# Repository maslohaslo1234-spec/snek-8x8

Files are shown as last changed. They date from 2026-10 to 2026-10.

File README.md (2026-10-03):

# Snek 8x8

A pocket-sized arcade console powered by an ESP32. It runs Snake on an 8x8 LED matrix and Flappy Bird on a 128x64 OLED display, with button controls, sound, and saved high scores.

ob

This project is being built for [Hack Club Half Life](https://halflife.hackclub.com/).

## Features

- Snake and Flappy Bird
- Three difficulty levels
- Optional walls in Snake, bonus food, and a high-score table
- High scores and settings saved between reboots
- English and Polish interface with a saved language preference
- Menu and in-game music, sound effects, and an idle screensaver

## Hardware

- ESP32 development board
- 8x8 LED matrix driven by two 74HC595 shift registers
- SSD1306 128x64 I2C OLED display
- Five push buttons on the PCB design; the current firmware uses three for game and menu controls.
- Buzzer
- Li-Po battery and power components

### Pin connections

| Part | ESP32 pin |
| --- | --- |
| 74HC595 data | GPIO 23 |
| 74HC595 latch | GPIO 16 |
| 74HC595 clock | GPIO 18 |
| OLED SDA | GPIO 21 |
| OLED SCL | GPIO 22 |
| SW1 (Up) | GPIO 33 |
| SW2 (Down) | GPIO 27 |
| SW3 (Left) | GPIO 14 |
| SW4 (Right) | GPIO 13 |
| SW5 (Action) | GPIO 26 |
| Buzzer control | GPIO 25 |

The button pins use `INPUT_PULLUP` and are wired between GPIO and GND, so pressed is LOW. SW1 and SW2 are sampled only to track activity and wake the screensaver; they do not control a game or menu. Check the pinout for your specific ESP32 board before wiring it. The buzzer is driven through a BC547 NPN transistor with a 1 kOhm base resistor; GPIO HIGH turns the buzzer on. Make sure the display, matrix drivers, and ESP32 share GND.

| Switch | GPIO | Planned function | Used by current firmware (yes/no) |
| --- | --- | --- | --- |
| SW1 | GPIO 33 | not used yet, reserved for Up/Down | No |
| SW2 | GPIO 27 | not used yet, reserved for Up/Down | No |
| SW3 | GPIO 14 | Left | Yes |
| SW4 | GPIO 13 | Right | Yes |
| SW5 | GPIO 26 | Action | Yes |

Here, "used" means used as a game or menu control; SW1 and SW2 are still sampled for activity/screensaver wake.

The 8x8 LED matrix was hand-soldered by me from a DIY kit.

### Hardware (work in progress)

[Schematic draft (PDF)](hardware/exports/snek_pcb_kicad.pdf)

Status: schematic draft v0.1 (power, charging, 5 buttons, buzzer, OLED, LED matrix), PCB layout not started.

The power design uses a Li-Po battery, a TP4056 charger module, a slide switch, and a 5V step-up converter. A Schottky diode is on the step-up output, which powers the ESP32 VIN pin.

## Controls

| Button | Snake | Flappy Bird |
| --- | --- | --- |
| Left | Turn left | Pause |
| Right | Turn right | Not used |
| Action | Pause; press again to resume | Flap |

While paused, hold Action for about one second to return to the menu. In menus, Left and Right move through the options and Action selects one. Change the interface language in Settings; the selection is saved between reboots.

Up and Down are reserved for a future full-D-pad update; they do not currently control Snake, Flappy Bird, or the menus.

## Build and upload

1. Install the Arduino IDE and the ESP32 board support package by Espressif.
2. Install the **Adafruit SSD1306** and **Adafruit GFX Library** libraries using the Arduino IDE Library Manager. `Wire` and `EEPROM` are provided by the ESP32 Arduino core.
3. Open `firmware/esp32_snake/esp32_snake.ino`. Keep the other `.ino` files in the same folder; the Arduino IDE uses them as part of the sketch.
4. Select your ESP32 board and port, then build and upload.

The firmware uses the ESP32 Arduino core 3.x timer API. If compilation fails around `timerBegin`, `timerAttachInterrupt`, or `timerAlarm`, check that the installed ESP32 core is version 3.x.

## Repository layout

- `firmware/esp32_snake/` - current ESP32 firmware
- `legacy/arduino_snake/` - earlier Arduino firmware, kept for reference
- `hardware/` - KiCad schematic/project files and `hardware/exports/` for schematic exports

## Project log

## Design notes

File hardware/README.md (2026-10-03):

# Hardware

The schematic defines the planned hardware for the Snek 8x8 console:

- ESP32
- 8x8 LED matrix driven by two 74HC595 shift registers
- SSD1306 OLED
- Buzzer driven through a BC547 transistor
- Five push buttons (SW1-SW5)
- Li-Po battery, TP4056 charger module, slide switch, 5V step-up converter, and a Schottky diode on the step-up output

[View the schematic PDF](./exports/snek_pcb_kicad.pdf).

**Status:** schematic draft v0.1, PCB layout not started, nothing on the PCB has been built or tested yet.

## differences between hardware design and firmware

- The schematic has five buttons, but only SW3 (Left), SW4 (Right), and SW5 (Action) are used as game/menu controls. SW1 (Up) and SW2 (Down) are sampled only for activity/screensaver wake; they do not control a game or menu yet.
- The schematic includes the battery charging and power-conversion components, but the firmware contains no battery or charging management/monitoring code.

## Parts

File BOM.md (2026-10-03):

# Snek 8x8 — bill of materials

<!-- Generated by Half Life from project cmup66916042c01s1dxs5xl8g. Edits here are overwritten on the next sync. -->
<!-- Generated: 2026-10-03T12:50:23.381Z -->

> [!NOTE]
> This parts list is mirrored from [Half Life](https://halflife.hackclub.com). Editing it here will not change the platform's copy, and the next sync overwrites this file.

| Week | Tier | Parts funding |
| --- | --- | --- |
| Warm-up | Tier 1 | $30.00 |

| Part | What it's for | Qty | Unit | Total | Vendor |
| --- | --- | --- | --- | --- | --- |
| [3.7V 1400mAh Li-Po Battery (Akyga)](https://botland.com.pl/akumulatory-li-pol-1s-37v/14160-akumulator-akyga-li-pol-1400mah-1s-37v-zlacze-jst-bec-gniazdo-54x34x7mm-5904422321970.html) | Main power source for the console | 1 | $6.50 | $6.50 | [Botland](https://botland.com.pl/akumulatory-li-pol-1s-37v/14160-akumulator-akyga-li-pol-1400mah-1s-37v-zlacze-jst-bec-gniazdo-54x34x7mm-5904422321970.html) |
| [Li-Po Charger Module TP4056 USB-C](https://botland.com.pl/ladowarki-do-akumulatorow-li-ion/16979-ladowarka-li-ion-hw-373-v121-tp4056-pojedyncza-cela-1s-37v-usb-typ-c-z-zabezpieczeniami-5904422326708.h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) | Charging the battery and over-discharge protection | 1 | $1.42 | $1.42 | [Botland](https://botland.com.pl/ladowarki-do-akumulatorow-li-ion/16979-ladowarka-li-ion-hw-373-v121-tp4056-pojedyncza-cela-1s-37v-usb-typ-c-z-zabezpieczeniami-5904422326708.h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) |
| [Slide Switch 2-position](https://botland.com.pl/przelaczniki-suwakowe-i-przesuwne/4839-przelacznik-suwakowy-mss-2245-2-pozycyjny-prosty-5904422304188.html) | Main power ON/OFF switch | 1 | $1.01 | $1.01 | [Botland](https://botland.com.pl/przelaczniki-suwakowe-i-przesuwne/4839-przelacznik-suwakowy-mss-2245-2-pozycyjny-prosty-5904422304188.html) |
| [Female Pin Headers](https://botland.com.pl/gniazda-szpilkowe-goldpin/20029-listwa-goldpin-1x40-zenska-raster-254mm-10szt-justpi-5904422329174.html) | Sockets for ESP32, OLED, and Matrix so they are removable from the PCB | 1 | $2.55 | $2.55 | [Botland](https://botland.com.pl/gniazda-szpilkowe-goldpin/20029-listwa-goldpin-1x40-zenska-raster-254mm-10szt-justpi-5904422329174.html) |
| [Custom PCB](https://jlcpcb.com) | Main circuit board connecting ESP32, OLED, LED matrix, TP4056 charger, and controls | 1 | $2.00 | $2.00 | [JLCPCB](https://jlcpcb.com) |
| [5V Step-Up Voltage Regulator](https://botland.com.pl/przetwornice-step-up/3686-przetwornica-step-up-5v-12-a-z-gniazdem-usb-5903351241304.html) | Steps up 3.7V Li-Po battery voltage to stable 5V for ESP32 it has USB because it was the cheapest | 1 | $1.34 | $1.34 | [Botland](https://botland.com.pl/przetwornice-step-up/3686-przetwornica-step-up-5v-12-a-z-gniazdem-usb-5903351241304.html) |
| [Miscellaneous Components](https://botland.com.pl) | Transistors, connectors, resistors, and basic circuit parts | 1 | $3.00 | $3.00 | [Botland](https://botland.com.pl) |
| **Parts subtotal** | — | — | — | **$17.82** | — |
| **Tax & shipping** | — | — | — | **$12.00** | — |
| **Total** | — | — | — | **$29.82** | — |

$0.18 left of the tier's funding.

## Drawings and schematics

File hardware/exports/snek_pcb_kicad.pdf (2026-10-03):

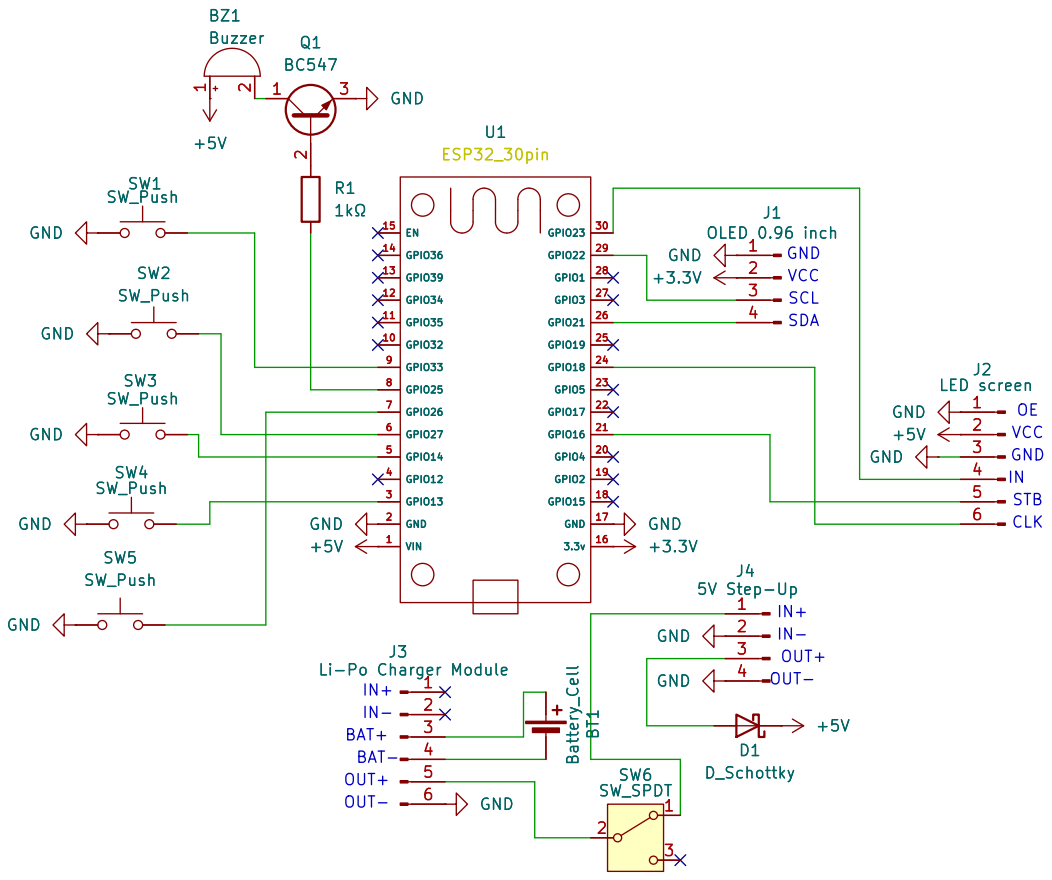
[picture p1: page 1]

Li-Po Charger Module 1

Size: A4 | Rev:
KiCad E.D.A. 10.0.6 | Id: 1/1

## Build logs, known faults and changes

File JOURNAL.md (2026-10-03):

# Snek 8x8 — devlog

<!-- Generated by Half Life from project cmup66916042c01s1dxs5xl8g. Edits here are overwritten on the next sync. -->
<!-- Generated: 2026-10-03T14:29:23.751Z -->

> [!NOTE]
> This devlog is mirrored from [Half Life](https://halflife.hackclub.com). Editing it here will not change the platform's copy, and the next sync overwrites this file.

> I'm building a pocket-sized handheld console that plays Snake on an 8×8 LED matrix, powered by an ESP32. The matrix isn't an off-the-shelf module. I soldered it myself from a DIY kit, LED by LED, which taught me a lot about how matrix displays are wired and driven. The console also has an OLED for score and menus and a buzzer for sound effects. The firmware is already fairly advanced: it has menus, sound and a two-language interface (Polish and English). I should be upfront that most of the code was written with AI assistance, because programming is not my strong side. My part of the project is the hardware: the soldering, wiring, electronics design and enclosure. That's also what I want to get better at in this program. I already have a working prototype on a breadboard. Now I want to turn it into a real, portable device: 	•	a custom PCB with the ESP32, the LED matrix, OLED, buzzer, buttons  	•	a 3D-printed enclosure designed in CAD, with a D-pad and action    buttons, 	•	clean power and wiring, so it works without a breadboard. My goal is to learn the full path from prototype to finished product: schematic, PCB layout, enclosure design and assembly. Parts: ESP32, hand-soldered 8×8 LED matrix, 0.96" OLED, buzzer, tact switches,  PCB, 3D-printed case.

| Week | Tier | Hours logged | Entries |
| --- | --- | --- | --- |
| Warm-up | Tier 1 | 14.5h | 3 |

## Contents

1. [2026-10-01 — ### Soldering the 8x8 LED matrix kit](#2026-10-01-soldering-the-8x8-led-matrix-kit)
2. [2026-10-01 — # From a dead chip to a playable console](#2026-10-01-from-a-dead-chip-to-a-playable-console)
3. [2026-10-03 — # Designing my first PCB: From breadboard to KiCad](#2026-10-03-designing-my-first-pcb-from-breadboard-to-kicad)

## Design

### 2026-10-01 — ### Soldering the 8x8 LED matrix kit

**3.5h**

### Soldering the 8x8 LED matrix kit

Bought a new soldering iron and wanted to test it, so I got a cheap Chinese practice kit: A41Z-DIY, a 64-LED SMD dot matrix board.

board

 No plan to build a game — just wanted to solder it and see if it worked. Soldered everything except the LEDs first

T,R

 then all 64 of them — only to find I'd put every single one in backwards. Desoldered and redid all 64

LEDs

 Then realized I'd lost the U1 chip that was supposed to drive the test animations, I couldn't actually test the board.

U1

kit

kit1

### 2026-10-01 — # From a dead chip to a playable console

**7h**

# From a dead chip to a playable console

After I lost the U1 chip from my kit, I realised the board still had header pins (OE, VCC, GND, IN, STB, CLK) connected directly to the two 74HC595 shift registers. That meant I could skip the missing chip and drive the matrix myself.

Jumper wires connected to the header pins of the matrix board

I connected an Arduino Nano and wrote a test sketch to turn on every LED. I was sure I had killed a few of them while soldering and desoldering, so seeing all 64 light up was a big surprise.

All 64 LEDs lit up during the Nano test sketch

With a working matrix and a few buttons on the breadboard, the obvious next step was Snake. I couldn't fit a plus-shaped D-pad on the breadboard layout, so the first version used just two buttons for relative movement (turn left / turn right).

First version of Snake running on the matrix

### Score, sound, and menus

I needed a place to show the score, so I added a 0.96" I2C OLED display. At first, it caused strange refresh problems and flickering. I fixed it by moving the matrix scanning into a hardware timer interrupt, writing to the shift registers using a custom fast shift-out function instead of `shiftOut()`, and swapping the frame buffer with interrupts temporarily disabled so a half-updated frame is never rendered.

OLED showing the score

Next came the buzzer: first a simple looping melody, then I found code for the Super Mario theme online and adapted it. That was easy, so I added Megalovania and the Tetris theme too.

Buzzer added to the breadboard

With several tracks, I needed a menu, so I built a simple UI on the OLED (one button moves the cursor, the other confirms). After that, I added three difficulty levels, two wall modes (walls kill you vs. wrap around), and bonus food spawning.

### Moving to ESP32

The Nano eventually became too limiting, so I moved everything to an ESP32. This was harder than I expected: the AVR timer tricks don't exist on the ESP32, so I had to rewrite the timer interrupt using the ESP32's native timer API. Also, to fix broken audio timing caused by the ESP32's 32-bit architecture, I removed the AVR-specific `PROGMEM` and `pgm_read_word()` calls, reading the note arrays directly from memory.

Circuit rebuilt around the ESP32

The upgrade was definitely worth it:
A third button: menus now use Right = Up, Left = Down, and Third = OK (in Snake, the controls still turn left/right). The third button also pauses the game, and a long press on the pause screen returns to the main menu.
Screensavers: idle animations run on both the OLED and the matrix when the console is left untouched.

Pause screen on the OLED

### Flappy Bird (a side experiment)

Once the ESP32 was running, I wanted a second game to see how flexible the system was. I picked Flappy Bird, but on an 8x8 matrix it's almost unplayable: the screen is only 8 pixels tall, so there's no room to see incoming pipes. My fix was rendering the game on **both displays at the same time**.

Flappy Bird shown on the OLED

Controls use the same setup: the action button flaps, and the left button pauses. It's less polished than Snake, so I treat it as a side experiment, but it proved the console can host multiple games.

### Saving data

High scores and settings are stored with the `EEPROM` library and `EEPROM.commit()`, so they survive power loss. Sound settings are stored separately for the main menu and for in-game audio.

### Where it stands

The whole prototype works, but it's still a tangle of breadboard wires:

The complete breadboard prototype on my desk

**Next step:** designing a custom PCB so everything works without the breadboard.

### 2026-10-03 — # Designing my first PCB: From breadboard to KiCad

**4h**

# Designing my first PCB: From breadboard to KiCad

Playing on the breadboard was becoming almost impossible because of all the loose wires constantly disconnecting, so I decided it was finally time to design a custom PCB.

I started out in EasyEDA. Since this was my first time ever creating a circuit schematic, I forgot quite a few basic things at the beginning, but I eventually managed to get a working draft.

First schematic draft in EasyEDA



Next, I wanted to try out KiCad, which had also been recommended to me. I started by recreating roughly the same schematic I had built in EasyEDA to get used to the software. In this version, I upgraded the controls to a 5-button setup: 4 buttons for a full D-pad and 1 action button.

KiCad schematic in progress

image_b0f565

While working on it, I realized it would be awesome to make the console fully portable by adding a battery and integrated charging. I hesitated at first, wondering if power management would make the design too complicated for my very first PCB, but I decided it was worth a shot.

Timelapse of designing the schematic in KiCad

polaczony-ezgif.com-video-to-gif-converter

I updated the schematic by adding a Li-Po battery connection, a TP4056 charger module, a 5V step-up voltage regulator to keep a stable supply for the ESP32, and a 2-position slide switch for power control.

Finished KiCad schematic with battery and power management

Zrzut ekranu 2026-10-03 154936

Next: PCB layout and routing

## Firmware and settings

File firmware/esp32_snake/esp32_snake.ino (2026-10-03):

#include <Wire.h>
#include <EEPROM.h>
#include <Adafruit_GFX.h>
#include <Adafruit_SSD1306.h>
#include <esp_system.h>
#include "pins.h"

#define SCREEN_WIDTH 128
#define SCREEN_HEIGHT 64
#define OLED_RESET -1
Adafruit_SSD1306 display(SCREEN_WIDTH, SCREEN_HEIGHT, &Wire, OLED_RESET);

const unsigned long BUTTON_DEBOUNCE_MS = 120;
const unsigned long IDLE_TIMEOUT_MS = 30000;
const unsigned long HOLD_EXIT_MS = 1000;
const int SPEED_UP_EVERY_FOODS = 4;
const int SPEED_UP_STEP_MS = 15;
const int MIN_GAME_SPEED_MS = 90;

// EEPROM address map.
const size_t EEPROM_SIZE = 36;
const byte EEPROM_MAGIC = 0xA8;
const int EEPROM_ADDR_MAGIC = 0;
const int EEPROM_ADDR_DIFFICULTY = 1;
const int EEPROM_ADDR_WALLS = 2;
const int EEPROM_ADDR_MUSIC_MENU = 3;
const int EEPROM_ADDR_MUSIC_GAME = 4;
const int EEPROM_ADDR_LANGUAGE = 5;
const int EEPROM_ADDR_HIGHSCORE_EASY = 8;
const int EEPROM_ADDR_HIGHSCORE_MED = 12;
const int EEPROM_ADDR_HIGHSCORE_HARD = 16;
const int EEPROM_ADDR_HIGHSCORE_FLAPPY = 20;

byte currentGame = 0; // 0: Snake, 1: Flappy Bird

byte snakeX[64];
byte snakeY[64];
byte snakeLen = 3;
byte foodX = 0;
byte foodY = 0;

byte bonusFoodX = 0;
byte bonusFoodY = 0;
bool isBonusFoodActive = false;
unsigned long bonusFoodTimer = 0;
const unsigned long BONUS_FOOD_DURATION_MS = 6000;
byte foodEatenCount = 0;

int score = 0;
int highScores[3] = {0, 0, 0}; // Snake: easy, medium, hard.
int highScoreFlappy = 0;
int currentDir = 1; // 0: up, 1: right, 2: down, 3: left.
bool dirChangedThisTick = false;
int gameSpeed = 350;
int scoreMultiplier = 1;
unsigned long gameStartTime = 0;
unsigned long gameEndTime = 0;
bool isNewHighScore = false;

bool gameStarted = false;
bool isPaused = false;
bool isGameOver = false;
bool isWinner = false;
bool isScreensaver = false;
bool oledDirty = true;

byte menuState = 0;              
byte mainMenuCursor = 0;         
byte settingsCursor = 0;
byte muzykaCursor = 0;           

byte difficultySetting = 1;
bool wallsEnabled = true;
byte languageSetting = 0; // 0: English, 1: Polish.

byte musicMenuTrack = 0;
byte musicGameTrack = 1;
byte currentPlayingTrack = 255;

const byte FB_PIPE_COUNT = 3;
float fbBirdY = 32;
float fbBirdVel = 0;
bool fbFlapQueued = false;
int fbPipeX[3];
int fbGapY[3]; // Vertical center of each gap.
int fbGapSize = 22;
int fbPipeW = 16;
int fbScrollSpeed = 2;
int fbBirdX = 28;
unsigned long lastFlappyFrame = 0;  

int ssX = 40, ssY = 28;
int ssDirX = 1, ssDirY = 1;
unsigned long lastSsMoveTime = 0;
const byte SS_TRAIL_LEN = 12;
int ssTrailX[12];
int ssTrailY[12];
int ssFoodX = 90, ssFoodY = 40;
int ssFoodDirX = -1, ssFoodDirY = 1;
byte ssMatFoodX = 7, ssMatFoodY = 3;
int ssMatFoodDir = 1;
byte ssMatFoodPos = 10;

bool isDeathAnimating = false;
byte deathAnimStep = 0;
unsigned long lastDeathAnimTime = 0;

bool lastLeftState = HIGH;
bool lastRightState = HIGH;
bool lastActionState = HIGH;
bool lastUpState = HIGH;
bool lastDownState = HIGH;
unsigned long lastActivityTime = 0;
unsigned long pauseActionPressTime = 0;
bool pauseExitTriggered = false;
bool pauseInputArmed = false; // Wait for ACTION to be released after entering pause.

unsigned long lastMoveTime = 0;
unsigned long lastButtonTime = 0;
unsigned long lastBlinkTime = 0;
bool blinkState = true;

unsigned long sfxEndTime = 0;
unsigned long lastMusicNoteTime = 0;
int currentMusicNoteIndex = 0;
unsigned long currentNoteDuration = 0;
bool isPlayingGameOverJingle = false;
unsigned long lastOledUpdateTime = 0;
const unsigned long OLED_UPDATE_MS = 35;

volatile byte displayBuffer[8];
volatile byte currentScanRow = 0;

void IRAM_ATTR writeMatrix(byte rows, byte columns);
void clearMatrixBuffer();
void setupMatrixTimer();

void setup() {
  pinMode(DATA_PIN, OUTPUT);
  pinMode(LATCH_PIN, OUTPUT);
  pinMode(CLK_PIN, OUTPUT);

  pinMode(BTN_LEFT_PIN, INPUT_PULLUP);
  pinMode(BTN_RIGHT_PIN, INPUT_PULLUP);
  pinMode(BTN_UP_PIN, INPUT_PULLUP);
  pinMode(BTN_DOWN_PIN, INPUT_PULLUP);
  pinMode(BTN_ACTION_PIN, INPUT_PULLUP);
  pinMode(BUZZER_PIN, OUTPUT);

  clearMatrixBuffer();
  writeMatrix(0xFF, 0xFF);

  randomSeed(esp_random()); 

  Wire.begin(OLED_SDA_PIN, OLED_SCL_PIN);
  if (!display.begin(SSD1306_SWITCHCAPVCC, 0x3C)) {
    for (;;);
  }

  Wire.setClock(400000L);
  display.clearDisplay();

  EEPROM.begin(EEPROM_SIZE);
  loadSettings();
  lastActivityTime = millis();

  setupMatrixTimer(); 
}

void loop() {
  handleInput();

  if (millis() - lastActivityTime > IDLE_TIMEOUT_MS && !gameStarted && !isScreensaver) {
    isScreensaver = true;
    ssX = 40;
    ssY = 28;
    ssDirX = 1;
    ssDirY = 1;
    ssFoodX = 96;
    ssFoodY = 20;
    ssFoodDirX = -1;
    ssFoodDirY = 1;
    ssMatFoodPos = 10;
    ssMatFoodDir = 1;
    ssMatFoodX = getPerimeterX(ssMatFoodPos);
    ssMatFoodY = getPerimeterY(ssMatFoodPos);
    for (byte i = 0; i < SS_TRAIL_LEN; i++) {
      ssTrailX[i] = ssX;
      ssTrailY[i] = ssY;
    }
    lastSsMoveTime = millis();
    noTone(BUZZER_PIN);
    oledDirty = true;
  }

  if (isScreensaver) {
    handleScreensaver();
  } else if (gameStarted && !isPaused) {
    if (currentGame == 1) {
      if (!isGameOver) updateFlappy();
    } else if (isDeathAnimating) {
      processDeathAnimation();
    } else if (!isGameOver) {
      if (millis() - lastMoveTime > gameSpeed) {
        lastMoveTime = millis();
        updateSnake();
      }
    }
  }

  if (millis() - lastBlinkTime > 300) {
    lastBlinkTime = millis();
    blinkState = !blinkState;
  }

  // Give the game-over jingle priority over background music.
  if (isPlayingGameOverJingle || isDeathAnimating) {
    playGameOverJingle();
  } else if (!isScreensaver && ((gameStarted && !isPaused && !isGameOver) || (!gameStarted && menuState > 0))) {
    playAsyncMusic();
  }
  
  updateDisplayBuffer();

  if (oledDirty && millis() - lastOledUpdateTime >= OLED_UPDATE_MS) {
    lastOledUpdateTime = millis();
    updateOLED();
    oledDirty = false;
  }
}

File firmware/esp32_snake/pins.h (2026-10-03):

#pragma once

#include <Arduino.h>

constexpr uint8_t DATA_PIN = 23;
constexpr uint8_t LATCH_PIN = 16;
constexpr uint8_t CLK_PIN = 18;

constexpr uint8_t OLED_SDA_PIN = 21;
constexpr uint8_t OLED_SCL_PIN = 22;

constexpr uint8_t BTN_UP_PIN = 33;    // SW1 exists on the PCB; not used by game/menu controls yet.
constexpr uint8_t BTN_DOWN_PIN = 27;  // SW2 exists on the PCB; not used by game/menu controls yet.
constexpr uint8_t BTN_LEFT_PIN = 14;
constexpr uint8_t BTN_RIGHT_PIN = 13;
constexpr uint8_t BTN_ACTION_PIN = 26;

constexpr uint8_t BUZZER_PIN = 25;

/*
 * Previous breadboard wiring:
 * DATA_PIN = 23, LATCH_PIN = 5, CLK_PIN = 18
 * BTN_LEFT_PIN = 32, BTN_RIGHT_PIN = 33, BTN_ACTION_PIN = 25
 * BUZZER_PIN = 26
 */

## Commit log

2026-10-03 Organize hardware files and update ESP32 pin map
    Move the schematic and export under hardware, centralize the revised PCB pin assignments, read all five buttons, and update the hardware documentation.
    [snek_pcb_kicad.kicad_sch]
2026-10-03 Clarify PCB buttons versus firmware controls
    Document that the design has five switches while only Left, Right, and Action drive current game and menu controls. Note that Up and Down are sampled only for activity and screensaver wake.
2026-11-08 Revise schematic description and add image
    Updated terminology from 'Schematic draft' to 'Schematic' and added an image.
